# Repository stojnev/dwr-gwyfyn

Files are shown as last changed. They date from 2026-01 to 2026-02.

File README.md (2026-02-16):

# dŵr-gŵyfyn

"dŵr-gŵyfyn" ("gŵyfyn") is a complete turntable tonearm designed for additive manufacturing, geared towards the highest performance. The project provides a set of models, ready-to-print settings and instructions for printing and assembling a full tonearm.

# Mounting

This is an approximate dimension diagram to understand if the tonearm will fit your requirements and space.

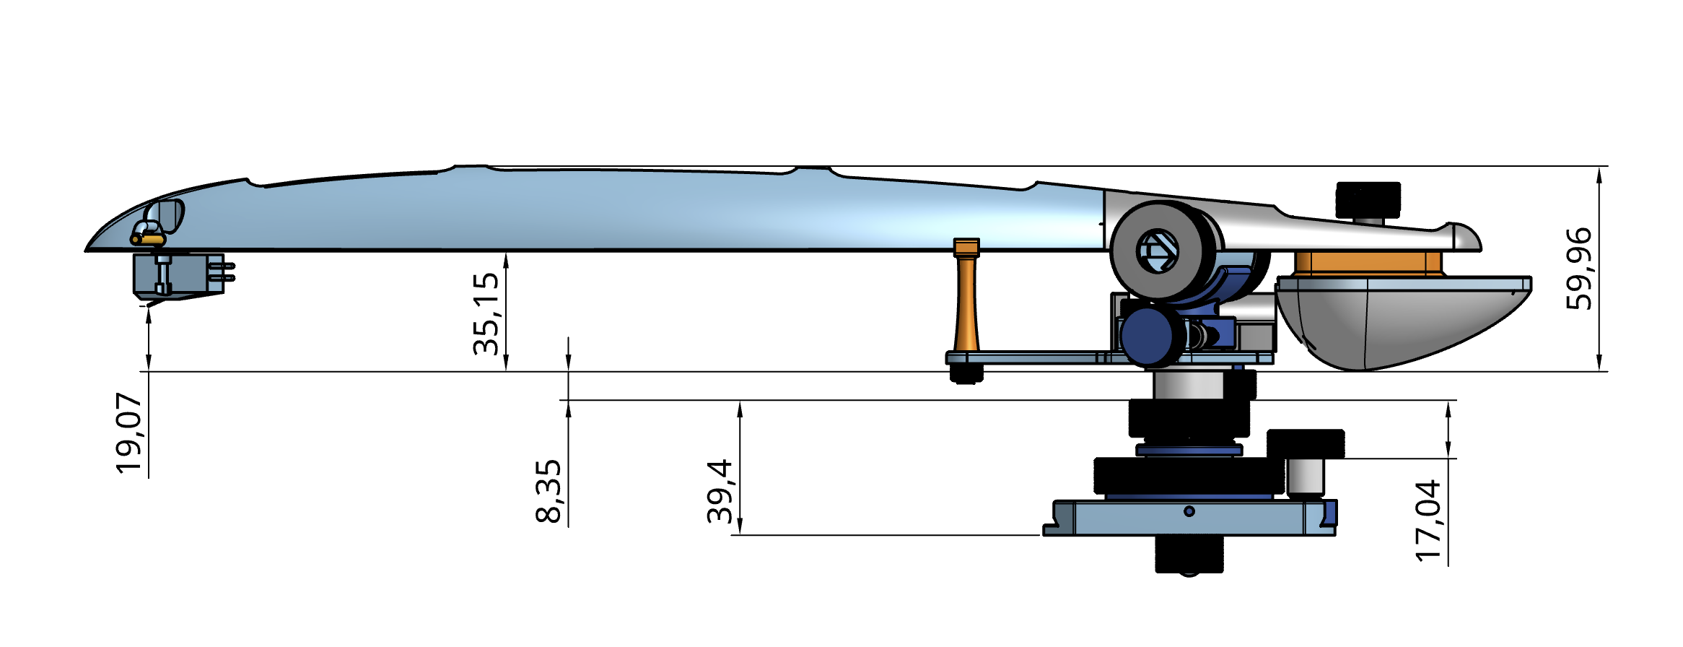
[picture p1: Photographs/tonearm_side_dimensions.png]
Tonearm


Please note that only height dimensions are provided since the tonearm can be printed in 9", 10" and 12" configurations.

# Order

The assemblies can be printed all at once, but it is recommended to print and assemble them in order which facilitates (I think) an easier completion.

The recommended order is as follows:

1. Base;
2. Pillar;
3. Rest;
4. Counterweight;
5. Flexures;
6. Tube;
7. Alignment.

# License

Shield: [][cc-by-nc-sa]

This work is licensed under a
[Creative Commons Attribution-NonCommercial-ShareAlike 4.0 International License][cc-by-nc-sa].

[][cc-by-nc-sa]

[cc-by-nc-sa]: http://creativecommons.org/licenses/by-nc-sa/4.0/
[cc-by-nc-sa-image]: https://licensebuttons.net/l/by-nc-sa/4.0/88x31.png
[cc-by-nc-sa-shield]: https://img.shields.io/badge/License-CC%20BY--NC--SA%204.0-lightgrey.svg

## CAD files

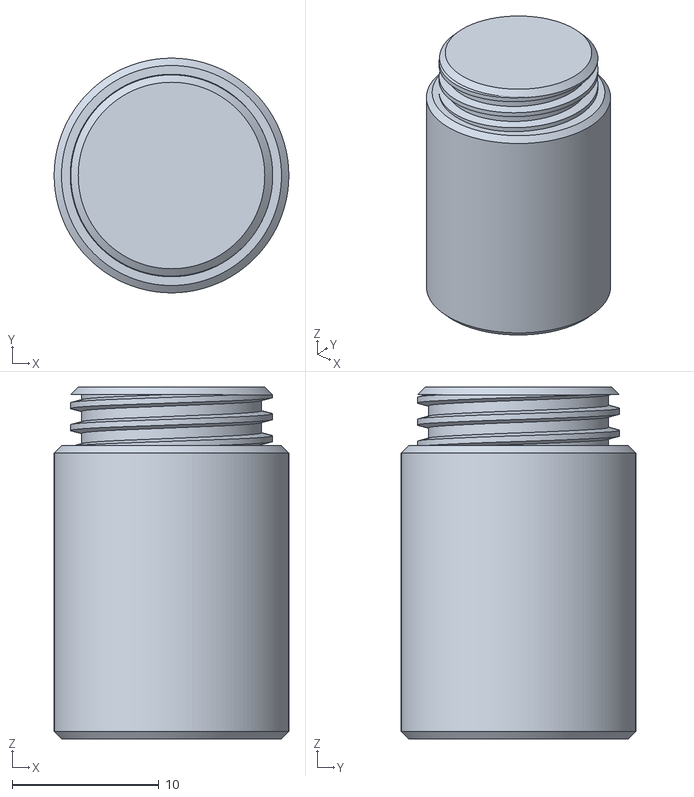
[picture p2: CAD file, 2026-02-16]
Alignment/Spindle Distance Jig/STL/Spindle Distance Jig - Spindle Adapter.stl
16.0 x 16.0 x 24.0

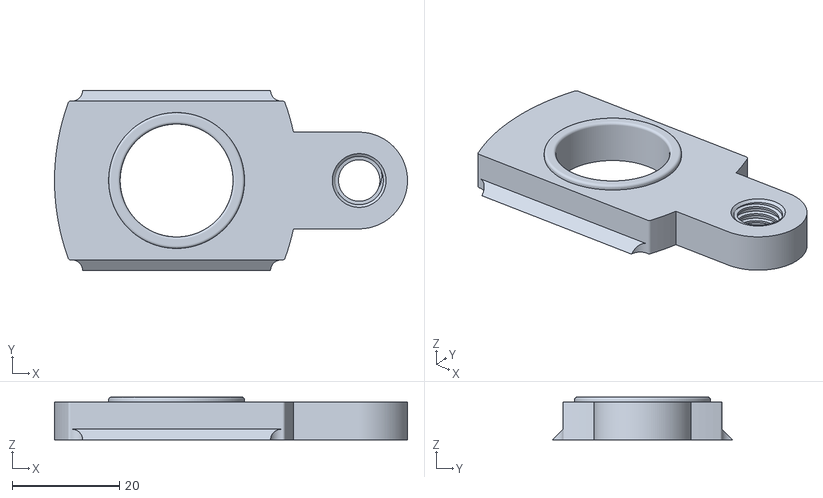
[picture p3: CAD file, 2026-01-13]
Base/STL/SME Mount - SME VTA Collar.stl
65.7 x 33.6 x 8.00

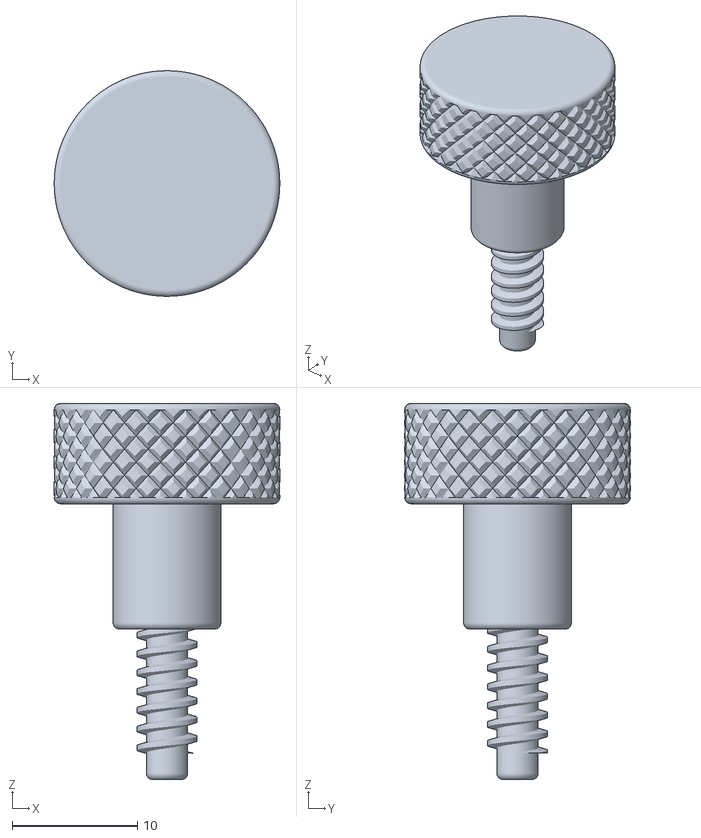
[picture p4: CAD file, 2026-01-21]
Counterweight/STL/Counterweight - Counterweight Lock.stl
18.0 x 18.0 x 30.0

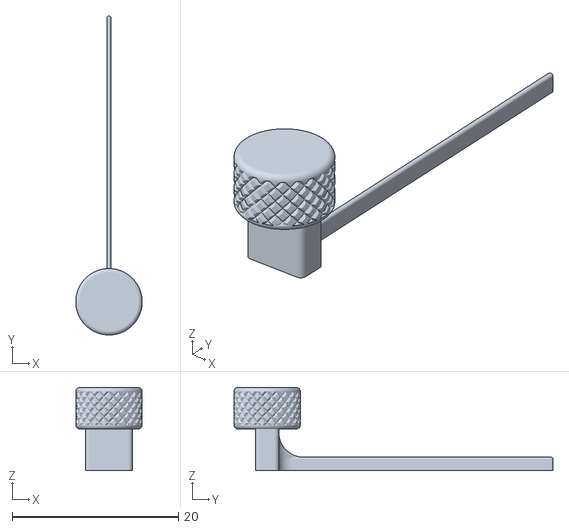
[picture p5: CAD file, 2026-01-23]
Flexures/STL/Linear Flexure.stl
8.00 x 38.4 x 10.0

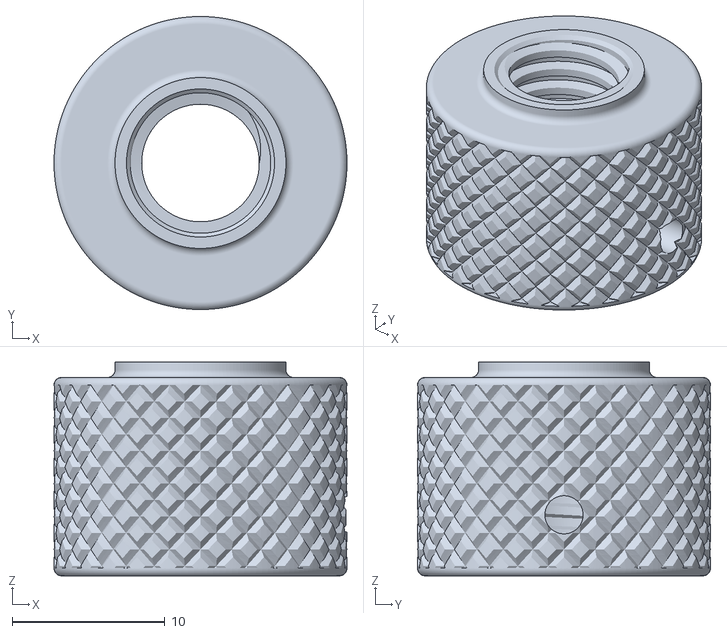
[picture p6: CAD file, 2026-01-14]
Pillar/STL/Tonearm Pillar - Pillar Cap.stl
19.2 x 19.2 x 14.0

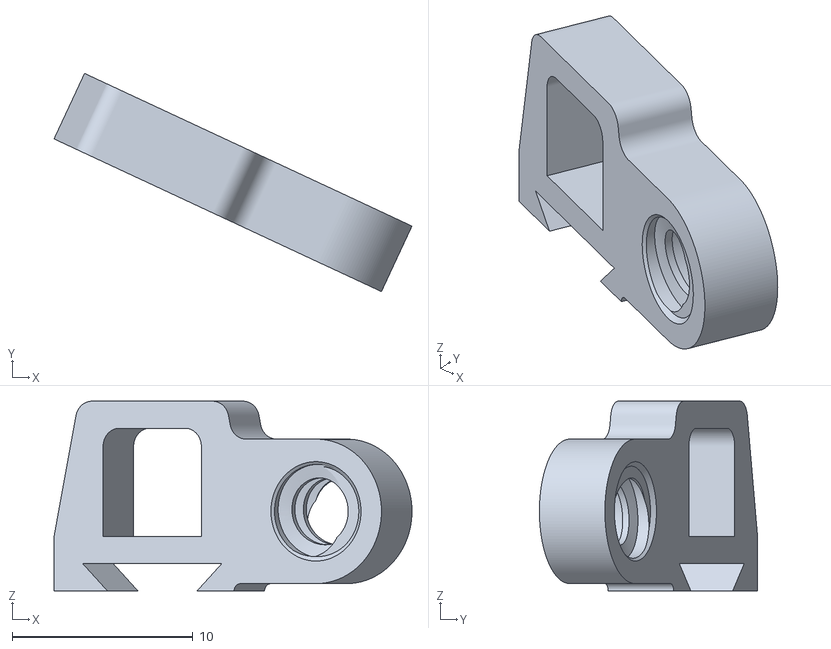
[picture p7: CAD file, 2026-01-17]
Rest/STL/Tonearm Rest Modular - Skating Slide.stl
19.8 x 12.1 x 10.5

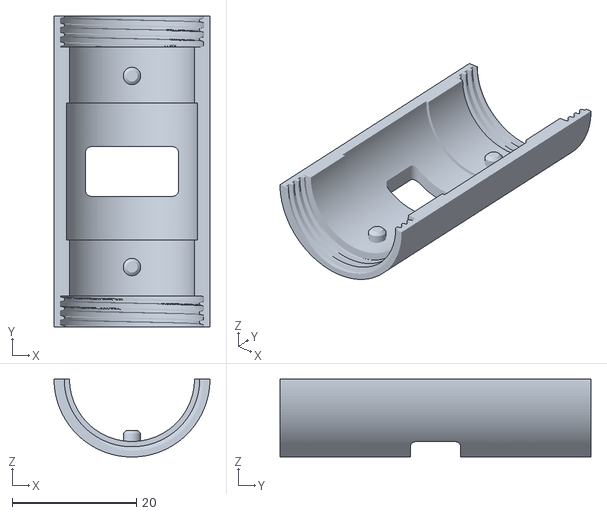
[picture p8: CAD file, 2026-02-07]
Tube/STL/Peripherals/Bearing Mount - Flexure Mount Bottom.stl
25.1 x 50.0 x 12.6

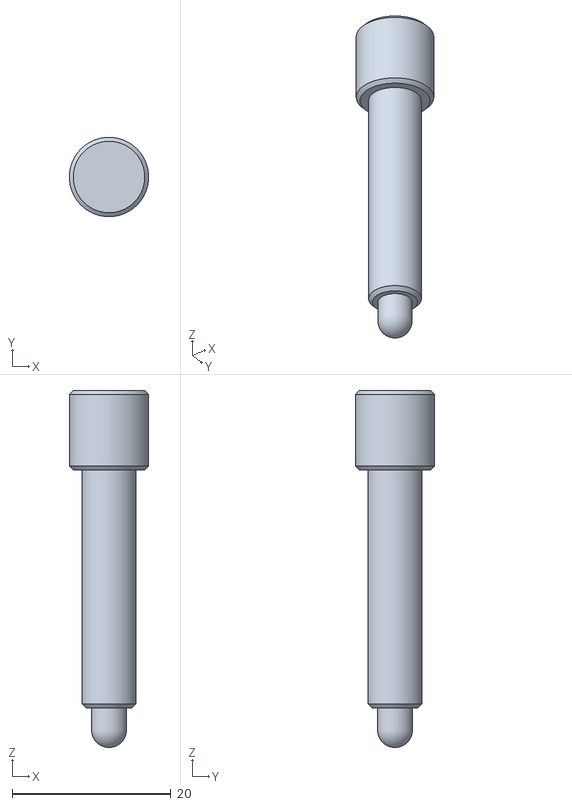
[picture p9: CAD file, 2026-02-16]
Alignment/Spindle Distance Jig/STL/Spindle Distance Jig - Locator Pin.stl
10.0 x 10.0 x 45.0

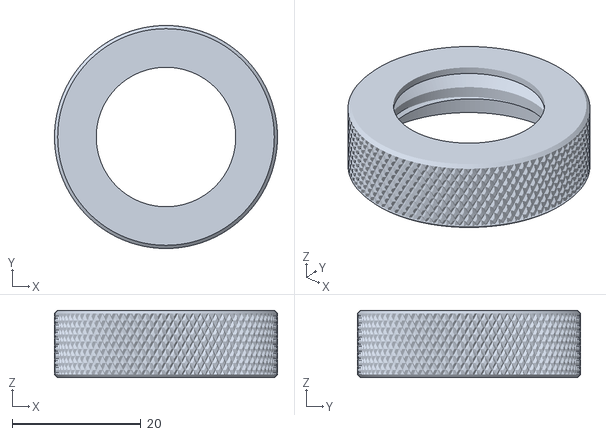
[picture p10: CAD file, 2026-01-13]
Base/STL/Tapered Clamp - Clamp Ring.stl
34.7 x 34.7 x 10.5

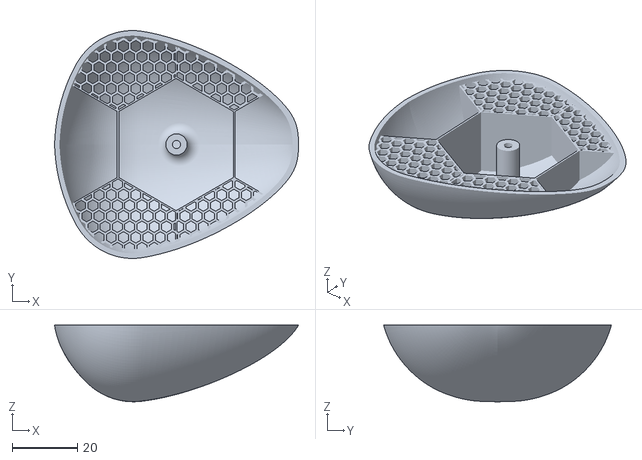
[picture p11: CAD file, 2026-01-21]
Counterweight/STL/Counterweight - Counterweight Body.stl
74.6 x 69.6 x 23.4

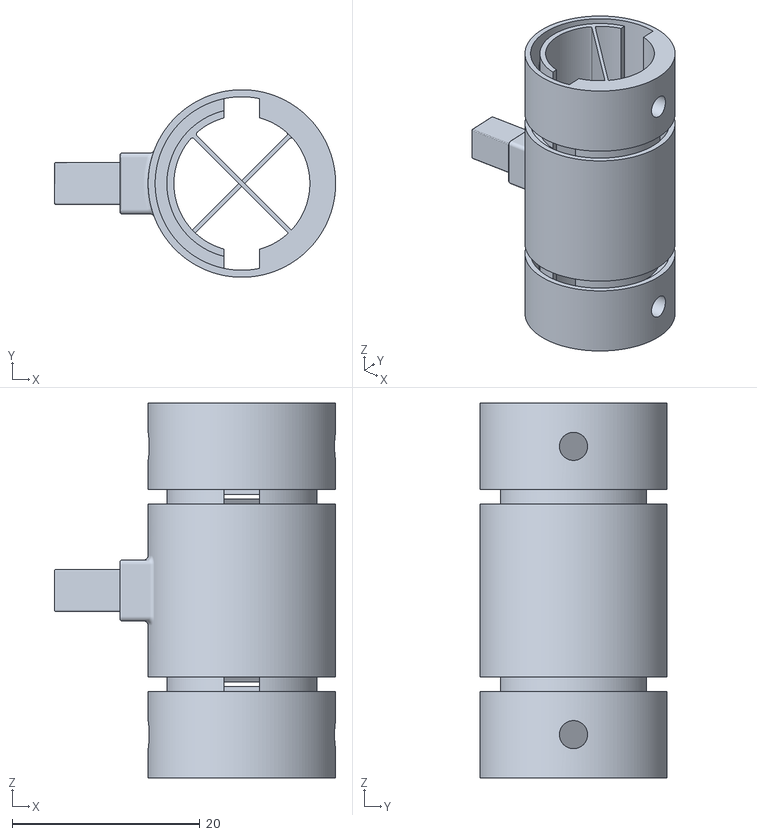
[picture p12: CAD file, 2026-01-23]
Flexures/STL/Circular Flexure.stl
30.0 x 20.0 x 40.0

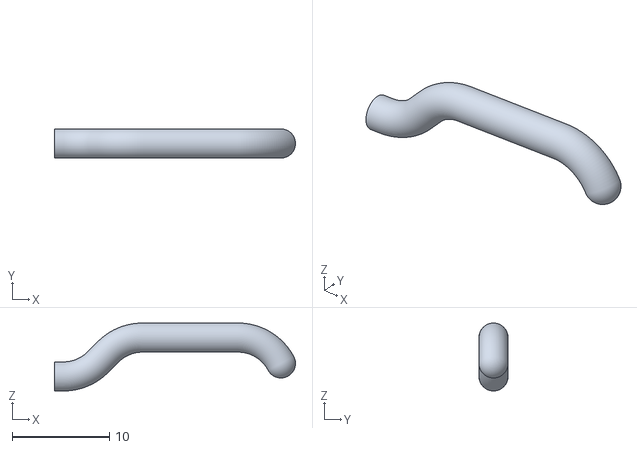
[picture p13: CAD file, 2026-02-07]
Tube/STL/Peripherals/Tube - Finger Lift Curved.stl
24.8 x 3.00 x 7.00

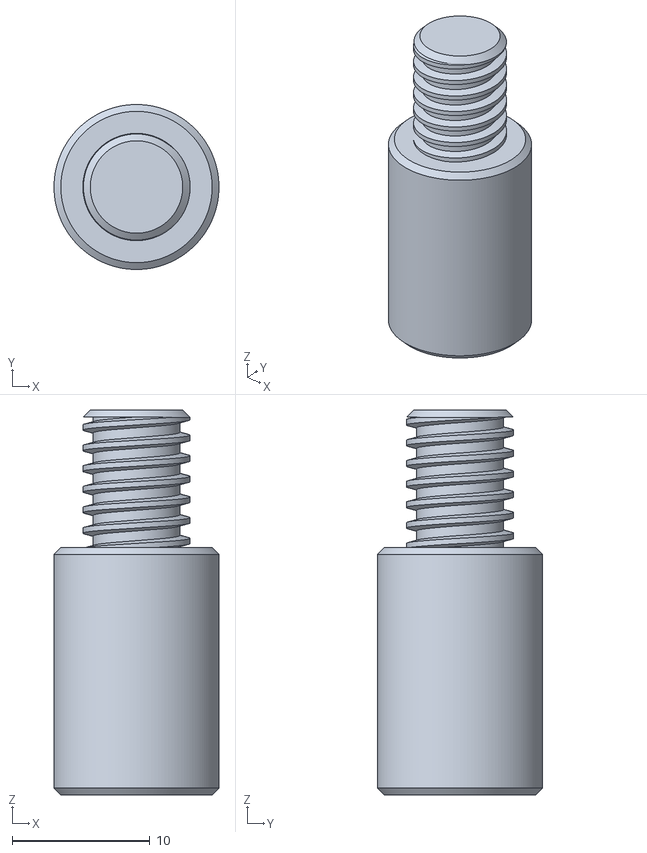
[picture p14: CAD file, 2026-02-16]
Alignment/Spindle Distance Jig/STL/Spindle Distance Jig - Support Column.stl
12.0 x 12.0 x 28.0

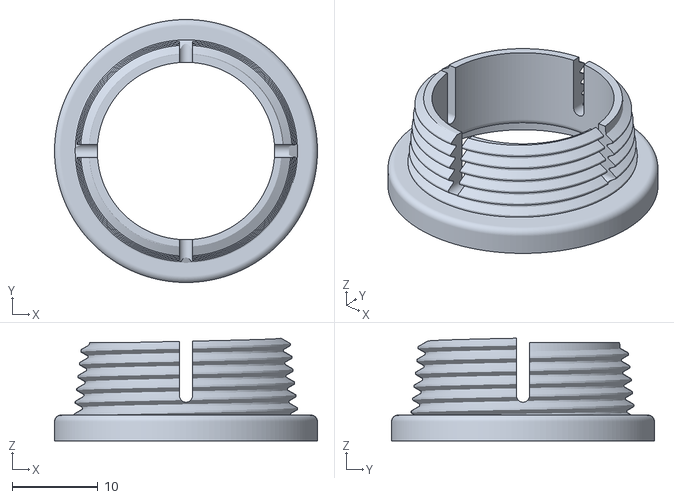
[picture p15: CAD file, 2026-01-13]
Base/STL/Tapered Clamp - Clamp Collar.stl
30.7 x 30.7 x 12.0

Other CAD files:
Counterweight/STL/Counterweight - Counterweight Slider.stl
Pillar/STL/Tonearm Pillar - Pillar Body.stl
Rest/STL/Tonearm Rest Modular - Tonearm Rest.stl
Tube/STL/Peripherals/Bearing Mount - Flexure Mount Cap.stl
Base/STL/Helicoidal VTA - Adjustment Ring.stl
Base/STL/Helicoidal VTA - Tonearm Collar.stl
Base/STL/Helicoidal VTA - VTA Base.stl
Base/STL/SME Fixed Mount - SME Fixed Mount.stl
Base/STL/SME Mount - Lock Bolt.stl
Base/STL/SME Mount - SME Base.stl
Base/STL/SME Mount - SME Clamp Collar.stl
Counterweight/STL/Counterweight - Counterweight Base.stl
Pillar/STL/Tonearm Pillar - Pillar Bolt.stl
Rest/STL/Tonearm Rest Modular - Connector Support.stl
Rest/STL/Tonearm Rest Modular - Cover Lock Bolt.stl
Rest/STL/Tonearm Rest Modular - Cover Lock Nut.stl
Rest/STL/Tonearm Rest Modular - Rest Bolt.stl
Rest/STL/Tonearm Rest Modular - Tonearm Plate.stl
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

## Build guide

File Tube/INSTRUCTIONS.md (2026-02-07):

# Tonearm Tube

This section deals with assembling the tonearm tube, in multiple configurations. Please refer to the individual assembly diagrams found in the `/Assemblies/` folder.

## Parts

There are two sets of parts, depending on configuration. The first set is needed regardless of configuration, the latter based on preference.

### Mounting Peripherals

- A - Bearing Mount - Flexure Mount Bottom.stl
- B - Bearing Mount - Flexure Mount Cap.stl
- C - Tube - Finger Lift Curved.stl

Print one of each, but print two of part B (mount cap).

### Tube Effective Length + Offset

There are two groups of parts based on the inclusion of bearing offset. Within those two groups, there are three individual configurations, based on effective length, and 9", 10" and 12" at that.

First you select either `/Bearing Offset/` for typical tonearms, or `/No Offset/` for tonearms with no bearing offset.

Once you do that, select either `/9 Inches/`, `/10 Inches/` or `/12 Inches/` based on effective length preference.

And once inside either of those folders, print one each of the following:

- D - Tube - Tonearm Stub.stl
- E - Tube - Tonearm Tube.stl

## Print Settings

All parts are printed using PLA, with the following settings:

- Layer Height: 0.16mm
- Initial Layer Height: 0.2mm
- Wall Loops: 6
- Top Shell Layers: 6
- Infill Density: 15%
- Infill Pattern: Honeycomb
- Supports: Minimal

## Tools

- CA Glue
- Xacto Knife
- Needle Nose Pliers

## Assemblies

1. Print parts A, B (two of these), C, D, and E.
2. Ensure that all internal suports within D and E have been removed. Use needle nose pliers if need be.
3. Glue D to E with a thin layer of CA glue, taking note that the wiring hole is not obstructed.
4. Take the counterweight slider found in the Counterweight assembly and glue it to the bottom of D using a thin layer of CA glue.
5. Once dried, take the circular flexure printed earlier, and press it within the section formerly known as E, now an integral part of the tube. There are pins on the underside of said sections, and openings on the circular flexure for proper locating.
6. Take A and press it to the underside of the flexure, and hold it in place.
7. Take both caps (B) and screw them on either side carefully noting the threads so that parallelism is maintained. These are internal threads so take extra care.
8. Once done, the flexure should be free to rotate and be visible from the openings in the caps.
9. Now take the entire assembly and push it onto the vertical flexure mount from the Pillar assembly.
10. If needed, glue C to the front of the tonearm tube in the locator hole.

At this point, you should have all printed and mounted parts, and proceed with wiring.

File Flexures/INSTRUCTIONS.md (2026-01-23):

# Tonearm Flexures

This section deals with the tonearm flexures.

## Parts

- A - Circular Flexure.stl
- B - Linear Flexure.stl

## Print Settings

All parts are printed using PLA, with the following settings:

- Layer Height: 0.16mm
- Initial Layer Height: 0.2mm
- Wall Loops: 6
- Top Shell Layers: 6
- Infill Density: 15%
- Infill Pattern: Honeycomb
- Supports: Minimal

## Tools

- CA Glue
- Xacto Knife

## Notes

Nothing to assemble at this point, just print out the flexures. I suggest printing a few copies of each to understand the level of flex available in relation to the material used.

The circular flexure may have some internal supports. Make sure you remove all of it carefully so that movement is not impeded.

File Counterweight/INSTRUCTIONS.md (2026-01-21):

# Tonearm Counterweight

This section deals with assembling the tonearm counterweight. Please refer to the individual assembly diagrams found in the `/Assemblies/` folder.

## Parts

- A - Counterweight - Counterweight Base.stl
- B - Counterweight - Counterweight Body.stl
- C - Counterweight - Counterweight Lock.stl
- D - Counterweight - Counterweight Slider.stl

## Print Settings

All parts are printed using PLA, with the following settings:

- Layer Height: 0.16mm
- Initial Layer Height: 0.2mm
- Wall Loops: 6
- Top Shell Layers: 6
- Infill Density: 15%
- Infill Pattern: Honeycomb
- Supports: Minimal

## Tools

- CA Glue
- Xacto Knife
- M3 Hand Tap [optional]
- 1 M3x10mm conical hex screw [optional]

## Assemblies

### Tonearm Counterweight

There are two parts to the counterweight, and two others for the slide. The counterweight is designed to slide in a dovetail and lock using a thumbscrew.

See `/Assemblies/Counterweight` for reference.

1. Print all parts.
2. Tap B on the preset hole using an M3 tap. This is optional and you may not need it if you glue the counterweight.
3. Put C and D aside - you will need them for the tube assembly.
4. Fill in some or all of the chambers of the counterweight body with leadshot.
5. Place A on top of B and either screw it with the M3 screw or glue it with a thin layer of CA glue.
6. Test out the dovetail and the thumbscrew to ensure smooth movement.

## Notes

The counterweight should be loosely filled. Leadshot is excellent in this manner, but it should not be packed - there is some performance to be gained from having the lead shot somewhat loose.

There is no way to accurately determine the amount of lead shot beforehand, as it varies in the type of lead shot you select, the effective length of the tonearm and additional factors. The main rule of thumb is to start with a few chambers, and add slowly until you reach a point where you have good travel of the counterweight.

Experimentation is key here.

This is why a screw could be suitable in the beginning, but once the proper amount of lead shot is determined, I recommend gluing the counterweight parts together.

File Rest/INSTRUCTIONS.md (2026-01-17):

# Tonearm Rest

This section deals with assembling the tonearm rest. Please refer to the individual assembly diagrams found in the `/Assemblies/` folder.

## Parts

- A - Tonearm Rest Modular - Connector Support.stl
- B - Tonearm Rest Modular - Cover Lock Bolt.stl
- C - Tonearm Rest Modular - Cover Lock Nut.stl
- D - Tonearm Rest Modular - Rest Bolt.stl
- E - Tonearm Rest Modular - Skating Bolt.stl
- F - Tonearm Rest Modular - Skating Slide.stl
- G - Tonearm Rest Modular - Tonearm Plate.stl
- H - Tonearm Rest Modular - Tonearm Rest.stl
- I - Tonearm Rest Modular - Wiring Cover DIN.stl
- J - Tonearm Rest Modular - Wiring Cover RCA.stl

## Print Settings

All parts are printed using PLA, with the following settings:

- Layer Height: 0.16mm
- Initial Layer Height: 0.2mm
- Wall Loops: 6
- Top Shell Layers: 6
- Infill Density: 15%
- Infill Pattern: Honeycomb
- Supports: Minimal

## Tools

- CA Glue
- Xacto Knife
- M3 Hand Tap [optional]

## Assemblies

### Tonearm Rest

Before printing, you need to decide if you want to have a DIN output connector, or a pair of RCAs. For option one, select I. For option two, select J.

See `/Assemblies/Tonearm Rest Modular` for reference.

1. Print all parts, and either I or J depending on your preferences.
2. Glue C to the bottom of I or J, in the designated depression.
3. Screw everything together, all of the parts are different.
4. Slide F on the dovetail of G.
5. Press E through the hole on G and screw on to the threads of F - this is a left hand thread.
6. Make sure that H points to the outside of the tonearm, on the side of the skating force compensation assembly.
7. Once done, take the bearing pillar out of the clamp and slide it throught he tonearm rest from the top, gently screwing it with care to the threads.

You can now insert the entire assembly in the clamp mount of your choice.

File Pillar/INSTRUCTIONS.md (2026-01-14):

# Tonearm Pillar

This section deals with assembling the tonearm pillar. Please refer to the individual assembly diagrams found in the `/Assemblies/` folder.

## Parts

- A - Tonearm Pillar - Flexure Mount Vertical.stl
- B - Tonearm Pillar - Pillar Body.stl
- C - Tonearm Pillar - Pillar Bolt.stl
- D - Tonearm Pillar - Pillar Cap.stl

## Print Settings

All parts are printed using PLA, with the following settings:

- Layer Height: 0.16mm
- Initial Layer Height: 0.2mm
- Wall Loops: 6
- Top Shell Layers: 6
- Infill Density: 15%
- Infill Pattern: Honeycomb
- Supports: Minimal

## Tools

- CA Glue
- Xacto Knife
- M3 Hand Tap [optional]
- 2 x 618/9 Rolling Bearing

## Assemblies

### Tonearm Pillar

This assembly holds the two vertical bearings together and provides an interface to the tonearm tube and horisontal bearings.

See `/Assemblies/Tonearm Pillar` for reference.

1. Print all parts.
2. Press the two bearings on each side of B. Make sure that the bearings are level - use a level surface to help install. Ensure free running.
3. Push C through the openings of the two bearings. It may be a tight fit, ensure that the bearings stay in place. Ensure free running.
4. Tap A and D on the preset holes using an M3 tap. This is optional and you may not need it depending on printer settings.
5. Screw D to the bottom thread of C once installed in B. Ensure free running. You are to use this cap as a setting for preload.
6. Once done, press A on the top of C using the pilot guides. Ensure free running. Ensure level positioning by checking runout.

You can now insert the entire assembly in the clamp mount of your choice.

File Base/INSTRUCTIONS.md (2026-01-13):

# Tonearm Base

This section deals with assembling the tonearm base, in multiple configurations. Please refer to the individual assembly diagrams found in the `/Assemblies/` folder.

## Parts

- A - Helicoidal VTA - Adjustment Ring.stl
- B - Helicoidal VTA - Tonearm Collar.stl
- C - Helicoidal VTA - VTA Base.stl
- D - SME Fixed Mount - SME Fixed Mount VTA.stl
- E - SME Fixed Mount - SME Fixed Mount.stl
- F - SME Mount - Lock Bolt.stl
- G - SME Mount - SME Base.stl
- H - SME Mount - SME Clamp Collar.stl
- I - SME Mount - SME VTA Collar.stl
- J - Tapered Clamp - Clamp Collar.stl
- K - Tapered Clamp - Clamp Ring.stl

## Print Settings

All parts are printed using PLA, with the following settings:

- Layer Height: 0.16mm
- Initial Layer Height: 0.2mm
- Wall Loops: 6
- Top Shell Layers: 6
- Infill Density: 15%
- Infill Pattern: Honeycomb
- Supports: Minimal

## Tools

- CA Glue
- Xacto Knife
- M3 Hand Tap [optional]

## Assemblies

### SME Fixed Clamp Mount

This assembly has the capability of a tapered clamp mount for the tonearm pillar, but NO provisions for tonearm height change, and NO provision for overhang change via slider.

See `/Assemblies/SME Fixed Clamp Mount` for reference.

1. Print parts E, J and K.
2. Locate J on the top protrusion of E, and glue with a thin layer of CA glue.
3. Once dried, screw provisionally K on top of J.

This will allow for compression of J via K and thus provide a clamping mount.

### SME Fixed VTA Clamp Mount

This assembly has the capability of a tapered clamp mount for the tonearm pillar, built-in tonearm height change, but NO provision for overhang change via slider.

See `/Assemblies/SME Fixed VTA Clamp Mount` for reference.

1. Print parts A, B, C, D, F, J and K.
2. Locate C on the top protrusion of D, and glue with a thin layer of CA glue.
3. Snap A on top of C;
4. Locate J on the top protrusion of B, and glue with a thin layer of CA glue.
5. Screw in the completed assembly from the previous step on the thread of A, noting it is a left hand thread.
6. Screw provisionally K on top of J.
7. Screw in F to the thread on D to allow for locking of the VTA assembly.

To clamp the tonearm, use the clamping mount.

To affect tonearm height, unscrew the lock bolt (F), turn in the adjustment collar (A) and after lock with the lock bolt.

### SME Sliding Clamp Mount

This assembly has the capability of a tapered clamp mount for the tonearm pillar, provision for overhang change via slider, but NO built-in tonearm height change.

See `/Assemblies/SME Sliding Clamp Mount` for reference.

1. Print parts G, H, J and K.
2. Locate J on the top protrusion of H, and glue with a thin layer of CA glue.
3. Use an M3 tap on the side of G for the set screw and insert a M3 set screw.
4. Slide the assembly with the base of H within the dovetail slot of G.

To clamp the tonearm, use the clamping mount.

### SME Sliding VTA Clamp Mount

This assembly has the capability of a tapered clamp mount for the tonearm pillar, provision for overhang change via slider, and built-in tonearm height change.

See `/Assemblies/SME Sliding VTA Clamp Mount` for reference.

1. Print parts A, B, C, F, I, J and K.
2. Locate C on the top protrusion of I, and glue with a thin layer of CA glue.
3. Snap A on top of C;
4. Locate J on the top protrusion of B, and glue with a thin layer of CA glue.
5. Screw in the completed assembly from the previous step on the thread of A, noting it is a left hand thread.
6. Screw provisionally K on top of J.
7. Use an M3 tap on the side of G for the set screw and insert a M3 set screw.
8. Slide the assembly with the base of H within the dovetail slot of I.

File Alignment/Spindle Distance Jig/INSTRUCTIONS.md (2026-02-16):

# Spindle Distance Jig

This section deals with setting up a spindle distance jig, to properly set pivot-to-spindle distance.

## Parts

There are two sets of parts, depending on configuration. The first set is needed regardless of configuration, the latter based on preference.

### Mounting Peripherals

- A - Spindle Distance Jig - Locator Pin.stl
- B - Spindle Distance Jig - Spindle Adapter.stl
- C - Spindle Distance Jig - Support Column.stl

Print one of each.

### Tube Effective Length

There are three files, depending on chosen effective length, meaning 9", 10" or 12". It makes no difference if there is any or no bearing offset.

- D - Spindle Distance Jig - Alignment Jig 9-.stl
- E - Spindle Distance Jig - Alignment Jig 10-.stl
- F - Spindle Distance Jig - Alignment Jig 12-.stl
- G - Spindle Distance Jig - Alignment Jig Universal.stl

## Print Settings

All parts are printed using PLA, with the following settings:

- Layer Height: 0.16mm
- Initial Layer Height: 0.2mm
- Wall Loops: 6
- Top Shell Layers: 6
- Infill Density: 15%
- Infill Pattern: Honeycomb
- Supports: Minimal

## Tools

- CA Glue
- Xacto Knife
- Needle Nose Pliers

## Assemblies

1. Print parts A, B, and C.
2. Print one of D, E, F or G depending on preference.
3. Screw B on the threaded end of your chosen jig from the previous step, all the way down.
4. Screw C on the middle portion in the threaded hole, but leave it loose.
5. Place B over your turntable spindle.
6. Unscrew C as needed in order to have the entire jig parallel to the platter.
7. Put A through either of the holes on the unsupported end of your chosen jig.
8. The thin end of the locator pin should slot neatly in the flexure mount on the tonearm pillar.

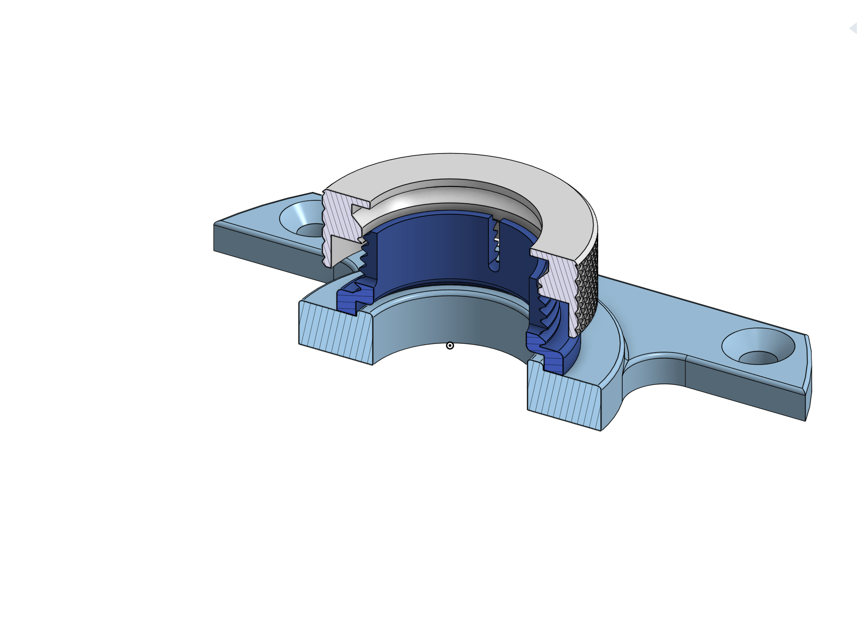
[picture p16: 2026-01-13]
Base/Assemblies/SME Fixed Clamp Mount [CUTOUT].png

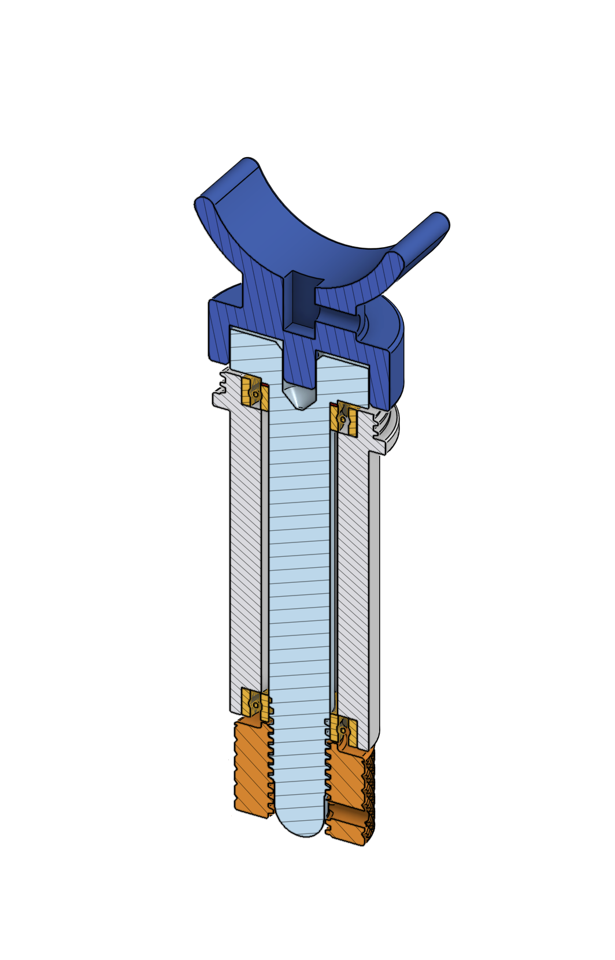
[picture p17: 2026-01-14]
Pillar/Assemblies/Tonearm Pillar [CUTOUT].png

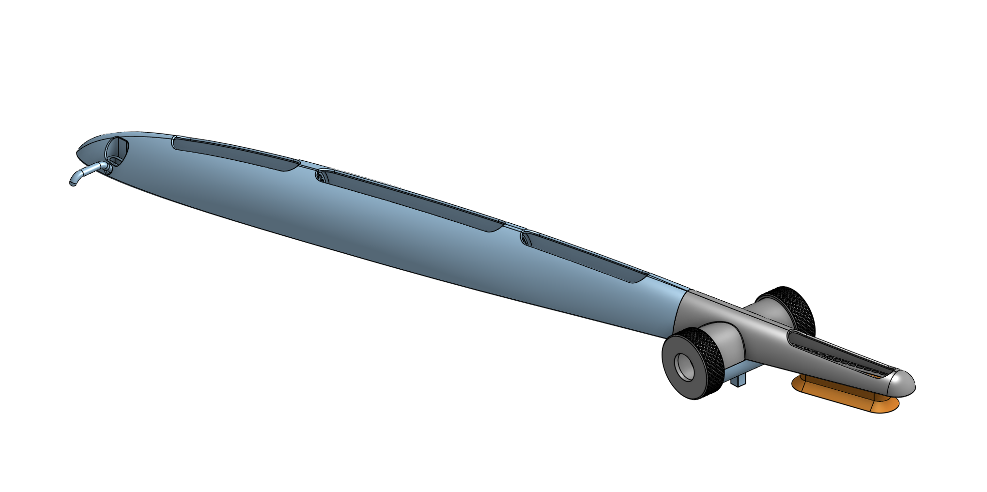
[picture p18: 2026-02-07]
Tube/Assemblies/Tonearm Tube.png

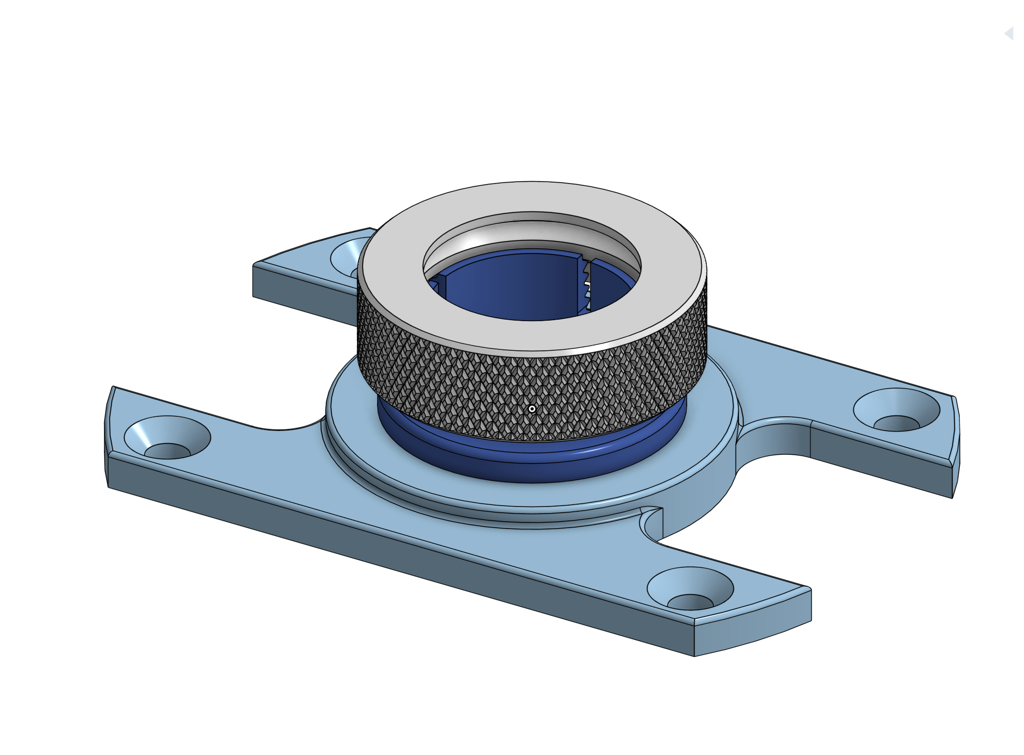
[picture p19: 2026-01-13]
Base/Assemblies/SME Fixed Clamp Mount [FULL].png

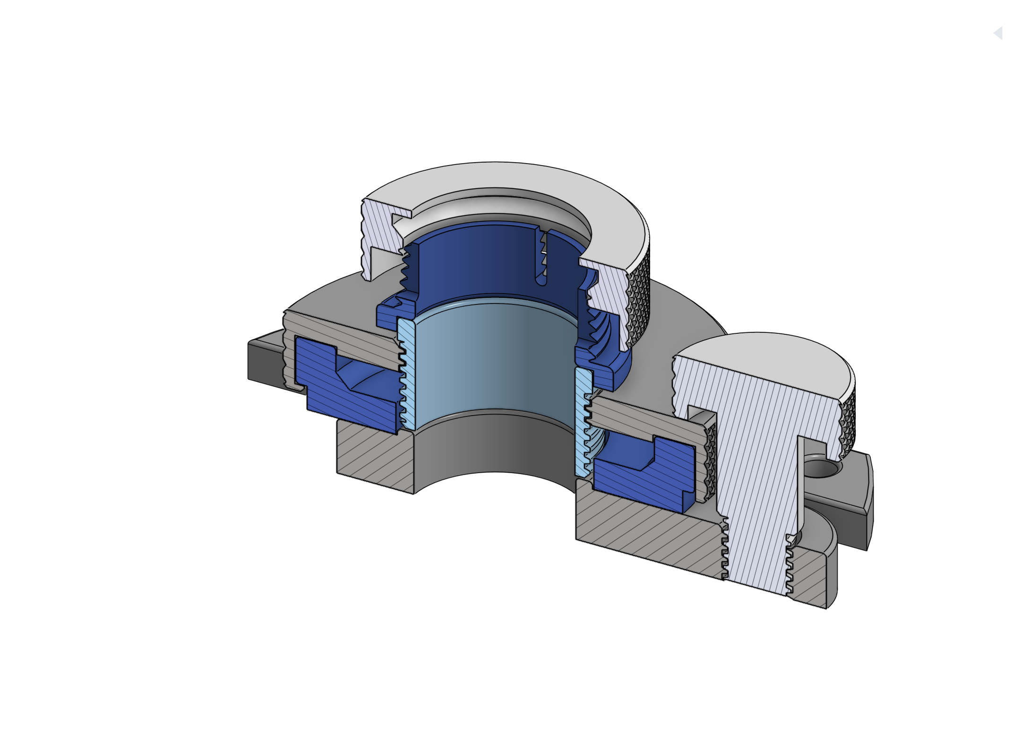
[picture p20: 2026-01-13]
Base/Assemblies/SME Fixed VTA Clamp Mount [CUTOUT].png

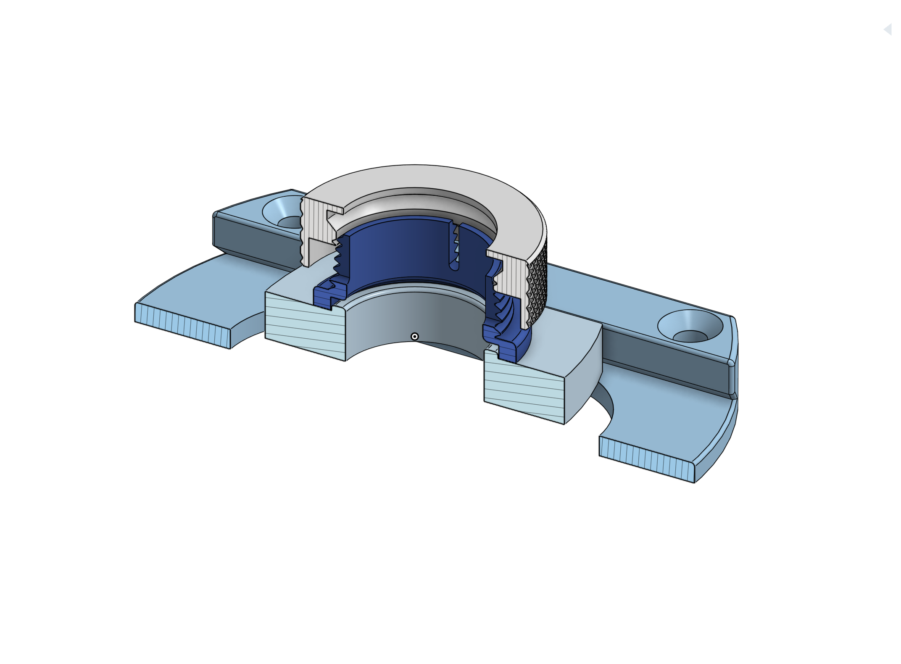
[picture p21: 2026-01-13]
Base/Assemblies/SME Sliding Clamp Mount [CUTOUT].png

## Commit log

2026-01-13 Add the components for Tonearm Base assemblies.
    [Helicoidal VTA - Adjustment Ring.stl, Helicoidal VTA - Tonearm Collar.stl, Helicoidal VTA - VTA Base.stl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]
2026-01-14 Add assemblies for tonearm pillar.
    [Tonearm Pillar - Pillar Body.stl, Tonearm Pillar - Pillar Bolt.stl, Tonearm Pillar - Pillar Cap.stl]
2026-01-14 Update assembly instructions for tonearm pillar.
2026-01-17 Add assemblies for tonearm rest and skating force compensation.
    [Tonearm Rest Modular - Connector Support.stl, Tonearm Rest Modular - Cover Lock Bolt.stl, Tonearm Rest Modular - Cover Lock Nut.stl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]
2026-01-21 Added the counterweight assembly.
    [Counterweight - Counterweight Base.stl, Counterweight - Counterweight Body.stl, Counterweight - Counterweight Lock.stl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]
2026-01-23 Added flexures.
    [Circular Flexure.stl, Linear Flexure.stl]
2026-01-23 Added instructions for printing flexures.
2026-02-07 Added the tube assemblies.
    [Bearing Mount - Flexure Mount Bottom.stl, Bearing Mount - Flexure Mount Cap.stl, Tube - Finger Lift Curved.stl]
2026-02-16 Added alignment tools.
    Added the necessesary parts for a jig to set proper spindle to pivot distance for the tonearm, in all three standard configurations.
    [Spindle Distance Jig - Locator Pin.stl, Spindle Distance Jig - Spindle Adapter.stl, Spindle Distance Jig - Support Column.stl]
2026-02-16 Updated alignment tools.
    Updated spindle to pivot distance jig to a universal format.
